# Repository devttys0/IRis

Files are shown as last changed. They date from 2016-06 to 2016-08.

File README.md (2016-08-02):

What?
=====

IRis is a low power, low cost, high sensitivity infrared detector designed for capturing raw IR digital data transmissions. Think of it like a mon0 interface for IR.

Why?
====

Typical [IR](https://www.sparkfun.com/products/10266) [receivers](http://dangerousprototypes.com/docs/USB_IR_Toy_v2) are designed to work with common IR remote controls, and as such they ignore any IR signals that are not [modulated at 36-38kHz](http://www.vishay.com/docs/80071/dataform.pdf). But there is so much more to the world of IR than this!

In contrast, IRis was designed to be a simple, general purpose IR detector to aid in the capture and analysis of raw IR transmissions, in particular low data rate signals such as those emitted by chell phone proximity sensors.

Who?
====

The brainchild of [Dale Wooden](https://www.linkedin.com/in/dale-wooden-1b1bb288), and designed by [Craig Heffner](http://www.analogzoo.com), IRis is of use to anyone interested in exploring the hidden world of IR around them!

How?
====

Most IR data is transmitted via on/off pulses (i.e., on-off keying). Powered from a single CR2032 coin cell battery, IRis uses a a sensitive photodiode, high gain transimpedance amplifier, and comparator to detect even very weak IR signals and convert them back into clean digital pulses that can be interpreted and analyzed by nearly any digital system, such as an Arduino or Raspberry Pi. Just connect to the IRis' output pins (connector P1) and point it at an IR source!

Due to its high sensitivity, best performance is obtained by preventing unwanted or ambient light from hitting the IRis photodiode. In conditions where there is low ambient light this is not a major problem, and in areas of greater illumination the issue can be mitigated by placing a shroud around the IR detector to prevent direct contact with unwated light. IR filters can also be used to reduce interference from unwanted light sources, but bear in mind that some bright light sources (e.g., the sun!) emit IR radiation as well.

IRis is still able to detect IR transmissions in the presence of bright ambient light, but at a reduced distance.

How Much?
=========

PCBs (1.24 inches in diameter) are available from [OSHPark](https://oshpark.com/shared_projects/OFeMS3Ed) for less than $8, and components can be ordered in single quantities from [Digikey](./digikey_bom.csv) for an additional $8.

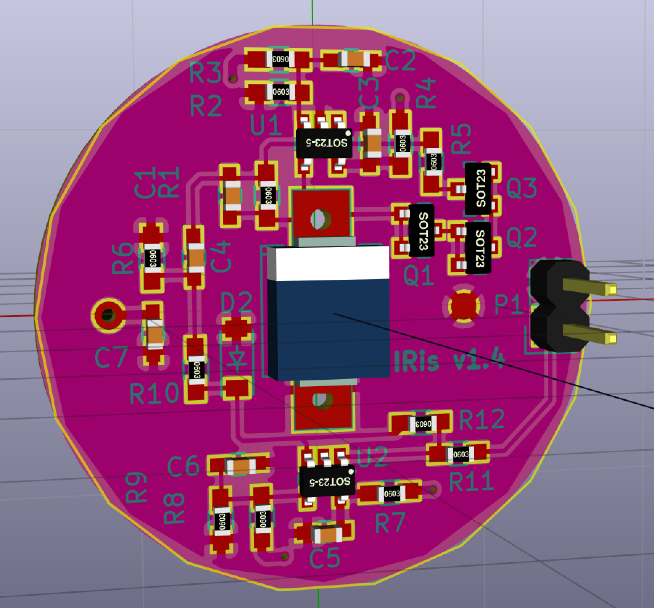
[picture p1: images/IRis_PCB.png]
IRis PCB 3D View


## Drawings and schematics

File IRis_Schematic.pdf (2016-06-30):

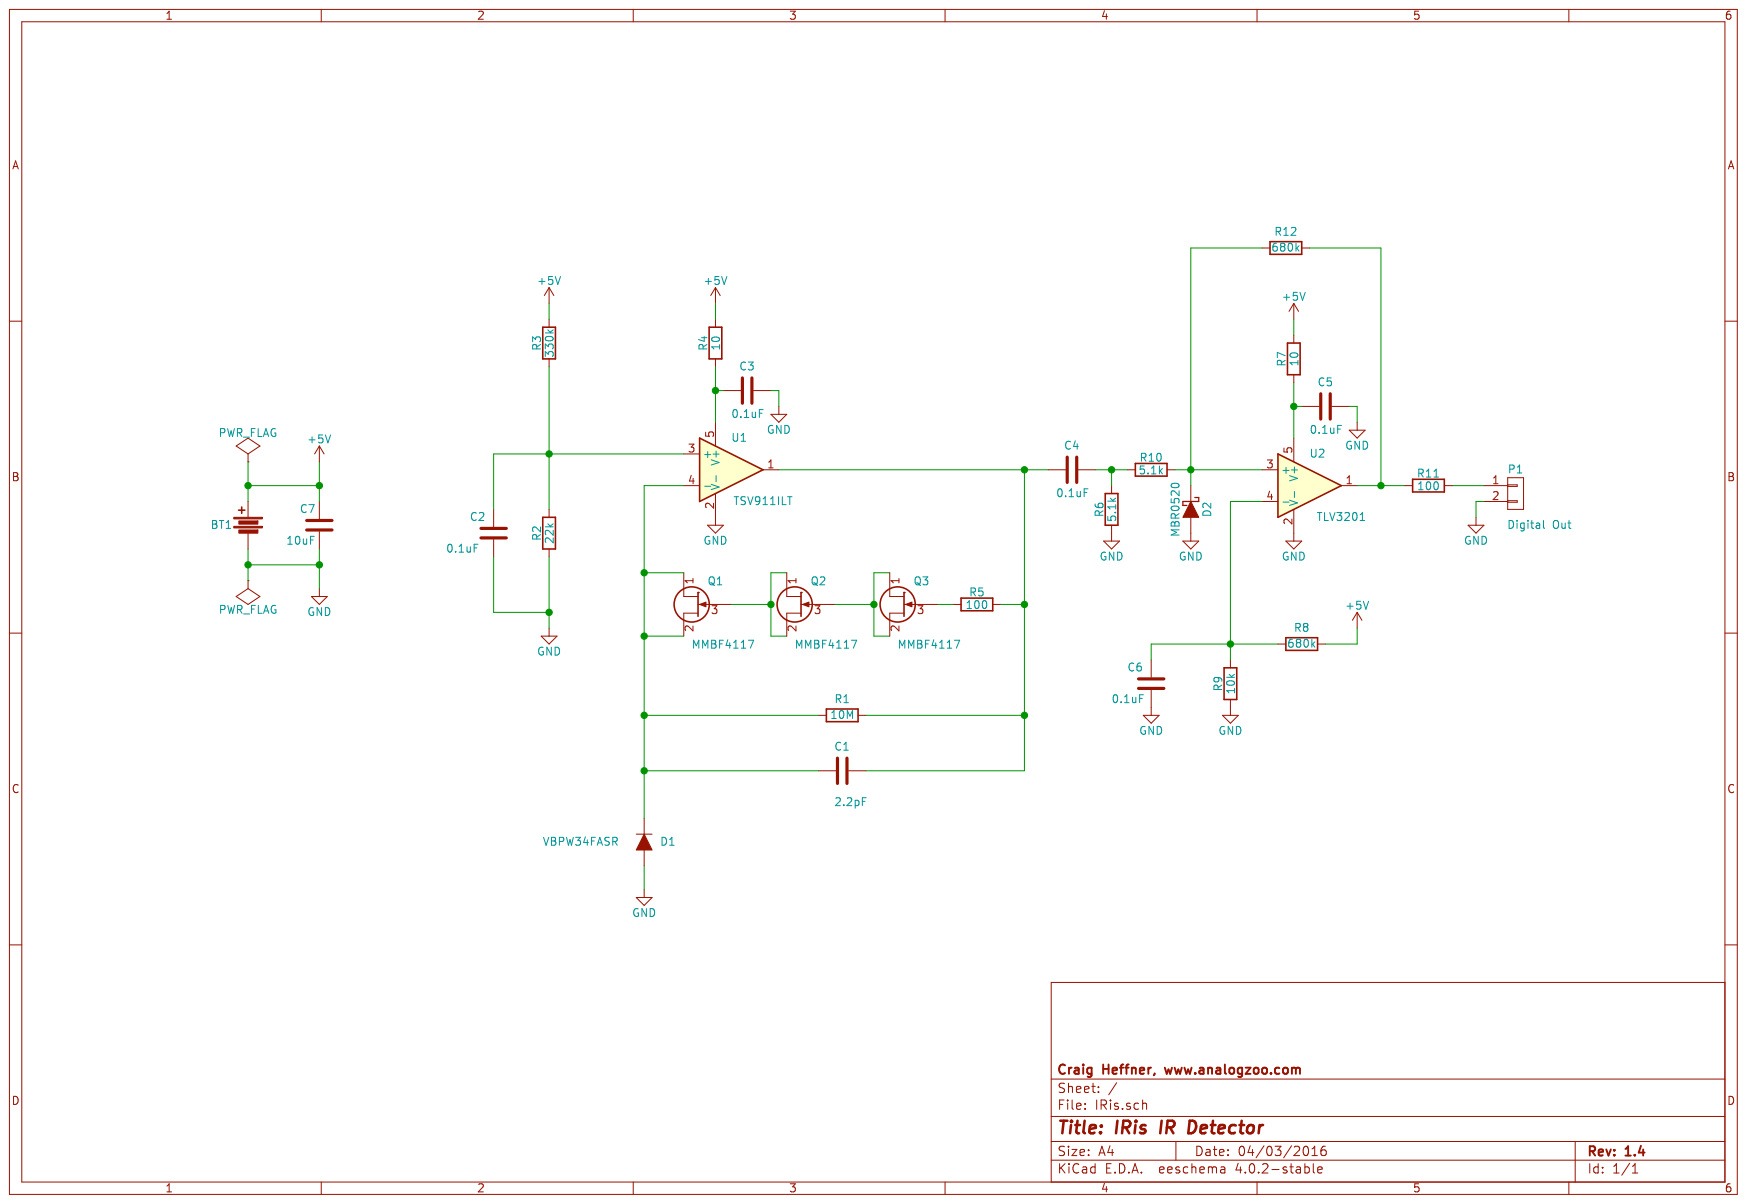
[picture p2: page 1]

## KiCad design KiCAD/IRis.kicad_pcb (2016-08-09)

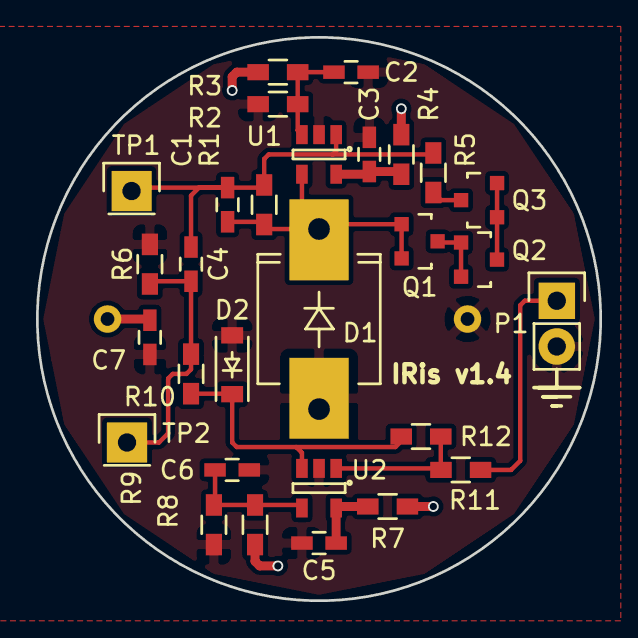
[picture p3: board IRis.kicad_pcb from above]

Board: 2 copper layers, 31.3 x 31.3 mm, 30 parts (1 on the bottom side), 15 nets.

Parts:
BT1: 3v; MPD BH32T-C
C1: 2.2pF; C_0603_HandSoldering
C2, C3, C4, C5, C6: 0.1uF; C_0603_HandSoldering
C7: 10uF; C_0603_HandSoldering
D1: VBPW34FASR; SMC-RM10_Universal_Handsoldering
D2: MBR0520; SOD-123
P1: Digital Out; Pin_Header_Straight_1x02
Q1, Q2, Q3: MMBF4117; SOT-23
R1: 10M; R_0603_HandSoldering
R2: 22k; R_0603_HandSoldering
R3: 330k; R_0603_HandSoldering
R4, R7: 10; R_0603_HandSoldering
R5: 0; R_0603_HandSoldering
R6, R10: 5.1k; R_0603_HandSoldering
R8, R12: 680k; R_0603_HandSoldering
R9: 10k; R_0603_HandSoldering
R11: 100; R_0603_HandSoldering
TP1: Test Point #1; Pin_Header_Straight_1x01
TP2: Test Point #2; Pin_Header_Straight_1x01
U1: TSV911ILT; SOT-23-5
U2: TLV3201; SOT-23-5

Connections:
+5V: BT1.1, C7.1, R3.2, R4.2, R7.2, R8.1
GND: BT1.2, C2.2, C3.1, C5.1, C6.2, C7.2, D1.2, D2.2, P1.2, R2.1, R6.1, R9.1, U1.2, U2.2
unnamed: C1.1, C4.2, R1.1, R5.2, TP1.1, U1.1
unnamed: C1.2, D1.1, Q1.1, Q1.2, R1.2, U1.4
unnamed: C2.1, R2.2, R3.1, U1.3
unnamed: C3.2, R4.1, U1.5
unnamed: C4.1, R6.2, R10.1, TP2.1
unnamed: C5.2, R7.1, U2.5
unnamed: C6.1, R8.2, R9.2, U2.4
unnamed: D2.1, R10.2, R12.2, U2.3
unnamed: P1.1, R11.2
unnamed: Q1.3, Q2.1, Q2.2
unnamed: Q2.3, Q3.1, Q3.2
unnamed: Q3.3, R5.1
unnamed: R11.1, R12.1, U2.1

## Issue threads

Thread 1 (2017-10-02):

MOSFETs Q1-3

bot1131357, 2017-10-02:
Hi there,

This is really more of an enquiry. Could you tell me what the three MOSFETs (MMBF4117) are doing in the circuit? As far as I can tell, they seem redundant to me.

Thanks!

devttys0, 2017-10-03:
Those are actually JFETs which are connected as diodes in the circuit. Their purpose is to prevent opamp U1 from saturating if its output voltage exceeds the voltage drop of the three PN junctions.

JFETs were originally chosen here to prevent reverse leakage, as they have very low-leakage properties compared with a typical silicon diode. However, in the final circuit there should never be a situation where they are reverse biased, so reverse leakage current really isn't a concern, and the JFETs can easily be replaced with a run-of-the-mill diode.

Closed 2018-01-16.

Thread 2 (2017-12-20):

5V and GND shorted

bot1131357, 2017-12-20:
Hi again,

I am experiencing some difficulties assembling the board. Somehow my +5V pad is shorted to GND.

When I look at the PCB editor, it shows that the B.Cu layer is connected to the +5V pad, but it also seemed to be connected to the circled GND pad.

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

(Also, would you be able to include in the documentation the correct output signal when the board is working?)

devttys0, 2018-01-16:
The top copper layer (which your circled ground pad is connected to) should be ground, and the bottom copper layer (which the +5V pad should be connected to) is Vcc.

Here is my view in KiCAD:

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

When viewed in 3D mode, it should be clear that the 5V pad is not connected to the top copper layer (ground):

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

Is this not the case for you?

bot1131357, 2018-01-16:
Thanks for the reply. Sorry I misread the diagram. The two other pieces where I've acquired from OSH Park works. I think the board I was testing on was faulty. Maybe I've damaged it somehow. I removed most of the components from the board, and yet 5V is still shorted to GND. Glad to get the other two pieces working though.

Closed 2018-01-16.

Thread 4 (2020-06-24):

OSHPark url for pcb doesn't work

mrUn1c0rn, 2020-06-24:
https://oshpark.com/shared_projects/OFeMS3Ed
gives 404 error

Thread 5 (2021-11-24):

Detection range of IR much shorter than of TV

JsBergbau, 2021-11-24:
First thanks for developing this great device.
I've build it and attached the signal output to active speakers. With that you can hear remote control of television when transmitting. In a quite dark room when facing the RC directly to IRis range is a few meters in which you can hear the RC. Despite it's digital output at some distance audio signal is clearly more quiet. Either signal is so weak that voltage output is lower or less impulses are detected so signal output is more quiet.

When putting IRis about 3.7 meters away from a window, facing at the window detection range is less than 50 cm. Detection range can be improved about 10 cm by applying a IR 760nm filter or putting a tube on, shielding the outside light, light the roles from toilet paper. There was no direct sunlight on IRis. Light measurement gave about 1200 lux at sensor angle. So it was not very bright and still range was reduced a lot.

I wonder how TVs can be remote controlled from a few meters distance even at very bright light conditions. So perhaps there is some possibility to increase detection range by using some technology like TVs do to increase detection range.

There is this cool project https://github.com/tb69rr/Iris using IRis to fingerprint smartphones. With higher detection range at daylight conditions it would get even more powerful.

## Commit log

2016-04-15 Initial check-in
    [IRis-B.Cu.gbr, IRis-B.Mask.gbr, IRis-B.SilkS.gbr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]
2016-05-05 Update to v1.3
    [IRis-B.Cu.gbr, IRis-B.Mask.gbr, IRis-B.SilkS.gbr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]
2016-05-21 Directory restructure.
    [IRis.kicad_pcb, IRis.sch]
2016-05-21 Added schematic PDF
2016-05-21 Added negative voltage input protection to comparator U2; fixed copper fill clearances for OSHPark
    [IRis.kicad_pcb, IRis.sch, digikey_bom.csv]
2016-05-22 Updated board and Gerbers to v1.4
    [IRis-B.Cu.gbr, IRis-B.Mask.gbr, IRis-B.SilkS.gbr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]
2016-06-06 Added external hysteresis to comparator
    [IRis.kicad_pcb, IRis.sch]
2016-06-30 Updated to latest version
    [IRis-B.Cu.gbr, IRis-B.Mask.gbr, IRis-B.SilkS.gbr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]
2016-08-08 Added ground icon to P1 silkscreen; rotated P1 180 degrees.
    [IRis.kicad_pcb]
2016-08-09 Changed R5 to zero-ohm jumper
    [IRis.sch]
2016-08-09 Added ground symbol to back silk screen of jumper P1.
    [IRis.kicad_pcb]
2016-08-09 Added test points TP1 and TP2 for monitoring the signal before and after DC blocking capacitor C4.
    [IRis.kicad_pcb, IRis.sch]
